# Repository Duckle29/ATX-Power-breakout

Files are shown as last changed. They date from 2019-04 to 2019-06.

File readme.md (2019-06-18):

# Pi ATX power breakout

This is just a simple board that breaks out the different rails of an ATX 24pin connector. It's mainly intented to be used for powering a Raspberry Pi and a 3D printer.

The board includes an EPS 4pin connector as well, allowing for up to 32A on the 12v rail. If you slightly overrun the rated 8A per cable, the 3 12v connectors will handle up to 36A (12A each). This is a 12.5% overload at 9A per cable. Most good cables/connectors should handle that.

The other rails can output 12A max, if the PSU can supply that on that rail.

The board also has a header for selecting how to control the PS_ON signal. It can either be controlled via a transistor controled by the RPi. Aditionally, the "Power Good" signal is also connected to the pi (through a voltage dividier).
Lastly, the I2C interface of the Pi is exposed on a 5 pin header, along with 5V 3V3 and Ground.

The 5V supply for the I2C connector and the Pi is selected through the the jumper JP1, while the 5V supply for the USB connector is selected via JP2. You can select between the 5V rail, or the 5V standby rail.

| Pin | Function |
|---|---|
| BCM17 | Power Good |
| BCM9  | Power On |
| BCM26 | BTN to GND |

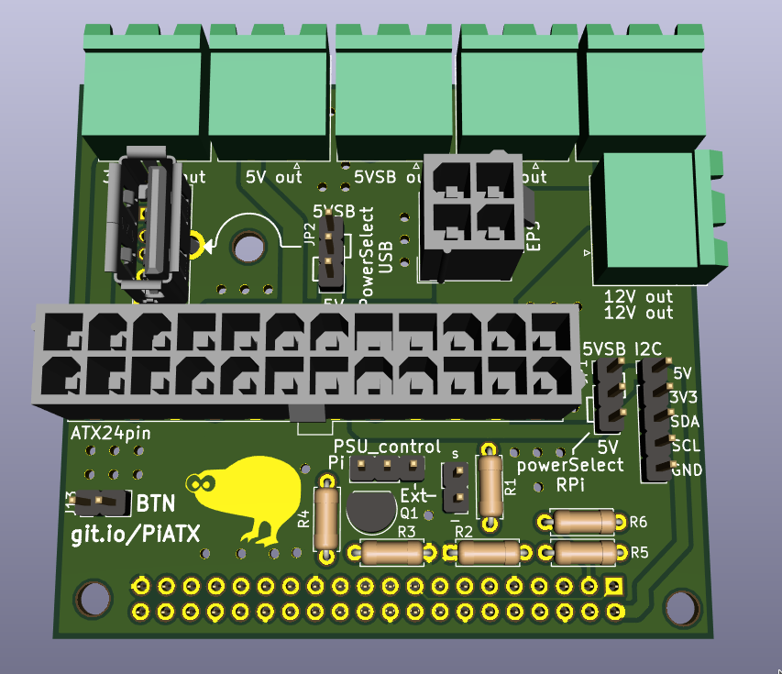
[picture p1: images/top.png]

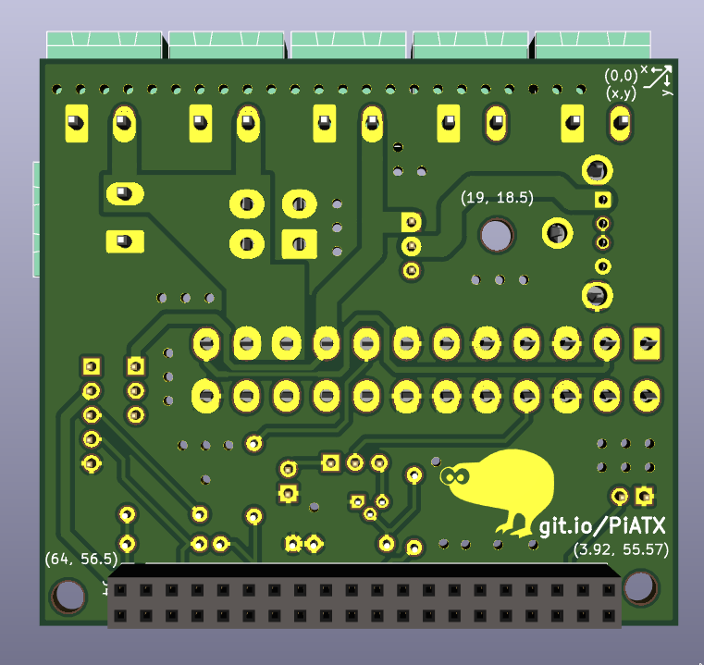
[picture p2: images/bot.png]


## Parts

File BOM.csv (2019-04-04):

Id | Designator | Package | Quantity | Designation | Supplier and ref
1 | REF**,REF**,REF** | MountingHole_3.2mm_M3_DIN965 | 3 | MountingHole_3.2mm_M3_DIN965
2 | R4 | R_Axial_DIN0207_L6.3mm_D2.5mm_P7.62mm_Horizontal | 1 | 1k
3 | J3 | USB_A_Stewart_SS-52100-001_Horizontal | 1 | USB_A
4 | G***,G*** | kiwi | 2 | LOGO
5 | J5 | Molex_Mini-Fit_Jr_5566-24A_2x12_P4.20mm_Vertical | 1 | ATX24pin
6 | J1 | PinHeader_1x05_P2.54mm_Vertical | 1 | I2C
7 | J2 | Molex_Mini-Fit_Jr_5566-04A_2x02_P4.20mm_Vertical | 1 | EPS
8 | J4 | PinSocket_2x20_P2.54mm_Vertical | 1 | Raspberry_Pi_2_3
9 | J7 | PinHeader_1x02_P2.54mm_Vertical | 1 | pson ext
10 | JP1,JP2 | PinHeader_1x03_P2.54mm_Vertical | 2 | powerSelect
11 | JP3 | PinHeader_1x03_P2.54mm_Vertical | 1 | PSU_control
12 | Q1 | TO-92 | 1 | Q_NPN_BCE
13 | J6,J11,J12 | PhoenixContact_MSTBA_2,5_2-G_1x02_P5.00mm_Horizontal | 3 | 12V out
14 | J8 | PhoenixContact_MSTBA_2,5_2-G_1x02_P5.00mm_Horizontal | 1 | 5V out
15 | J9 | PhoenixContact_MSTBA_2,5_2-G_1x02_P5.00mm_Horizontal | 1 | 5VSB out
16 | J10 | PhoenixContact_MSTBA_2,5_2-G_1x02_P5.00mm_Horizontal | 1 | 3V3 out
17 | R1 | R_Axial_DIN0207_L6.3mm_D2.5mm_P7.62mm_Horizontal | 1 | 5K6
18 | R2,R3,R5,R6 | R_Axial_DIN0207_L6.3mm_D2.5mm_P7.62mm_Horizontal | 4 | 10k

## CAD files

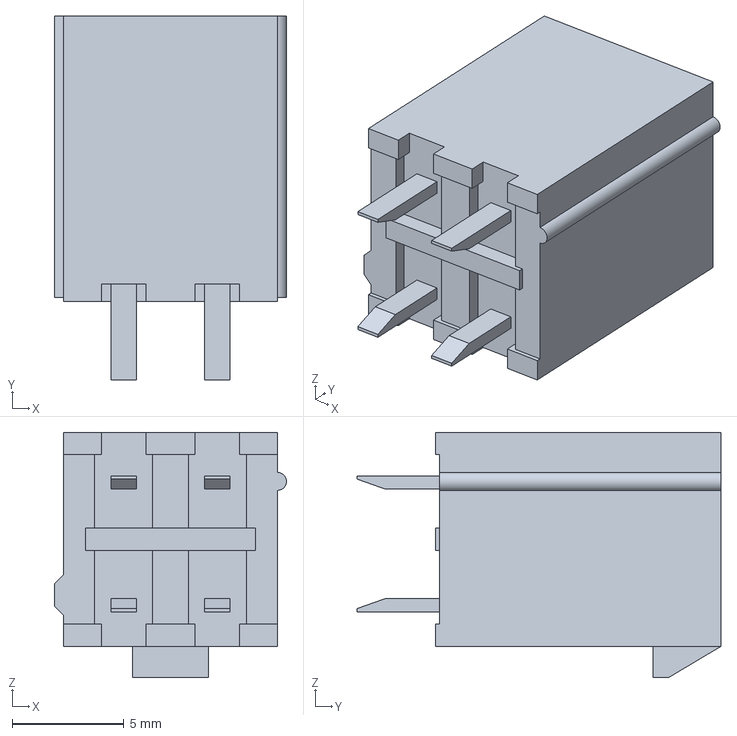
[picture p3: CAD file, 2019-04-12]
third-party-models/039281043.stp
10.4 x 16.3 x 11.0 mm

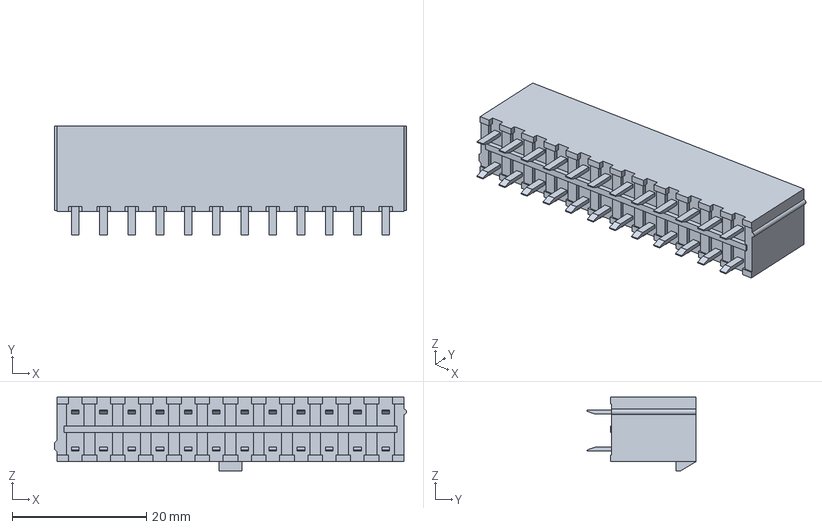
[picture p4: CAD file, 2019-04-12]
third-party-models/039281243.stp
52.4 x 16.3 x 11.0 mm

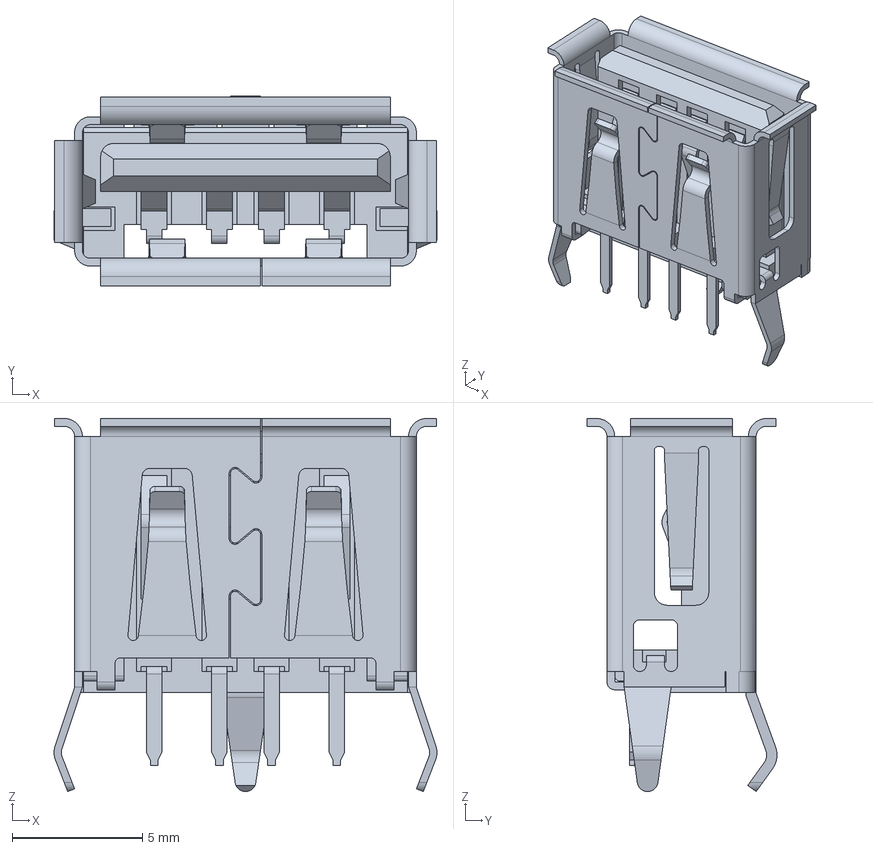
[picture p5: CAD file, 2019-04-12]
third-party-models/1050570001.stp
14.7 x 7.28 x 14.3 mm

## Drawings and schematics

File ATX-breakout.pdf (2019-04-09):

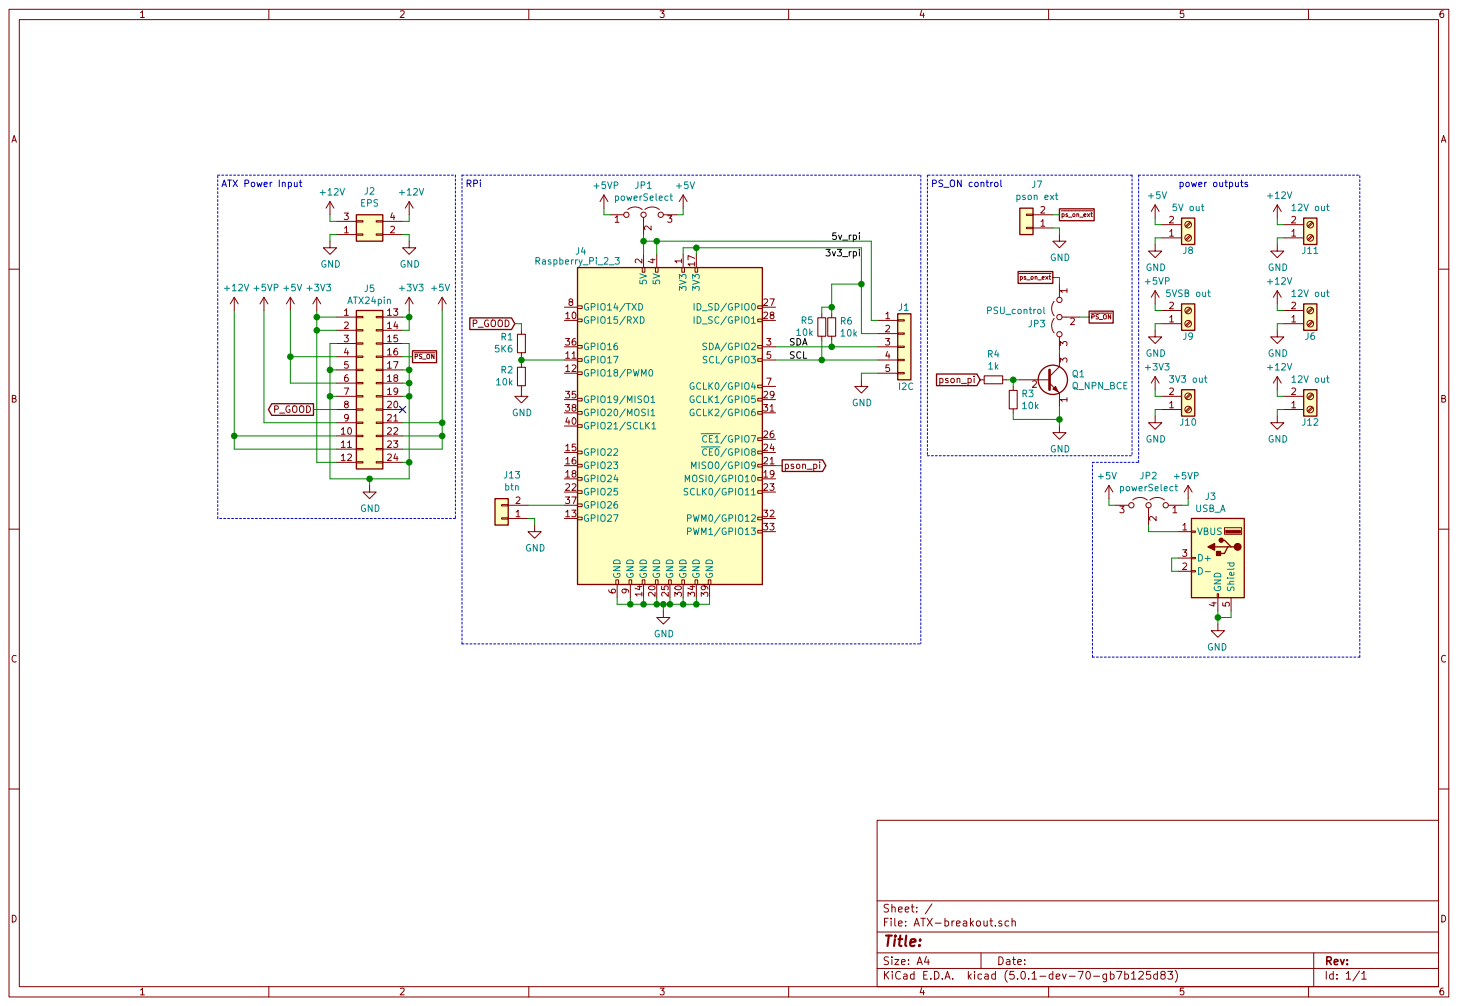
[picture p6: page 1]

10 | | 22
11 | | 23
12

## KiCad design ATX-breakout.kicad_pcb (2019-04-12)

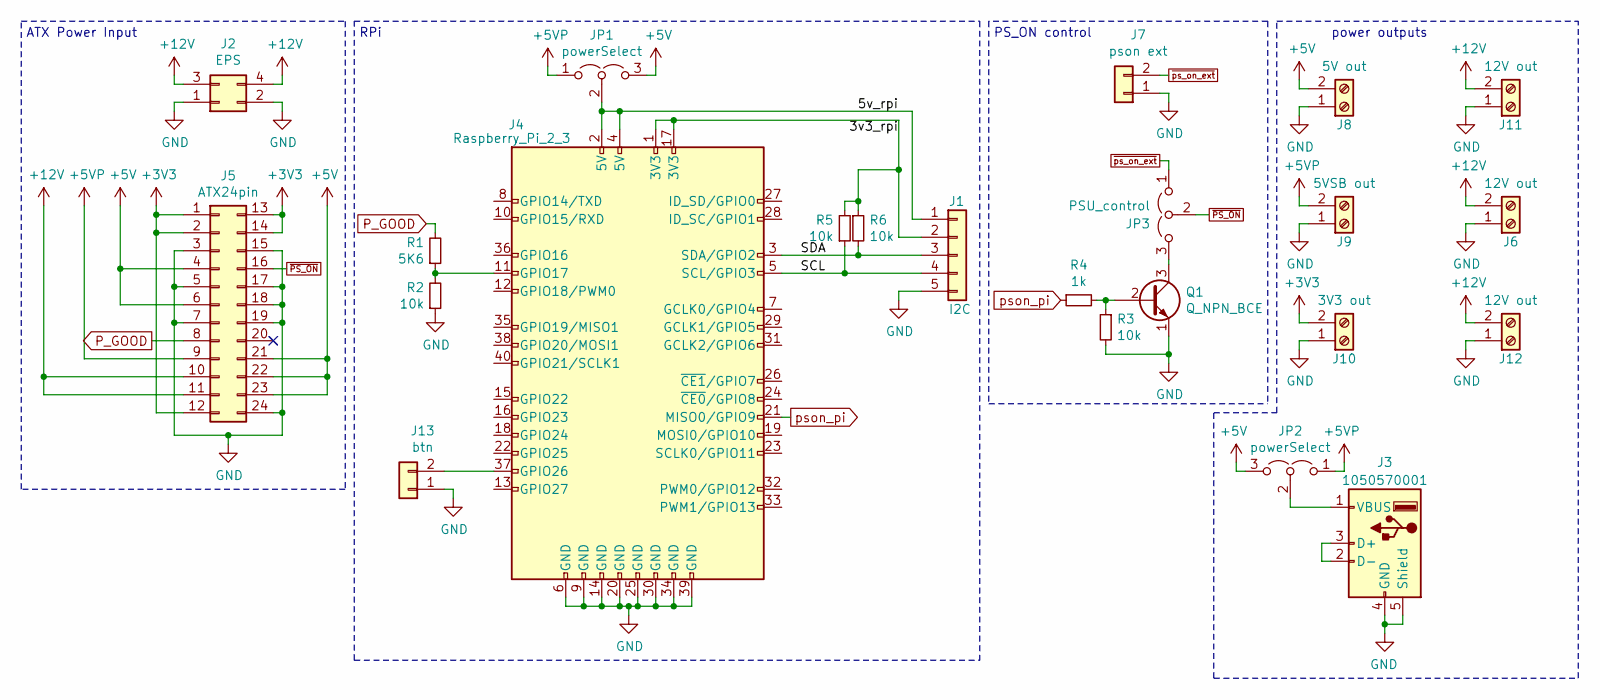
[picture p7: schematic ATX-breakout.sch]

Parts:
J1: I2C; PinHeader_1x05_P2.54mm_Vertical
J2: EPS; Molex_Mini-Fit_Jr_5566-04A_2x02_P4.20mm_Vertical
J3: 1050570001; USB_A_Molex_105057_Vertical
J4: Raspberry_Pi_2_3; PinSocket_2x20_P2.54mm_Vertical
J5: ATX24pin; Molex_Mini-Fit_Jr_5566-24A_2x12_P4.20mm_Vertical
J6, J11, J12: 12V out; PhoenixContact_MSTBA_2,5_2-G_1x02_P5.00mm_Horizontal
J7: pson ext; PinHeader_1x02_P2.54mm_Vertical
J8: 5V out; PhoenixContact_MSTBA_2,5_2-G_1x02_P5.00mm_Horizontal
J9: 5VSB out; PhoenixContact_MSTBA_2,5_2-G_1x02_P5.00mm_Horizontal
J10: 3V3 out; PhoenixContact_MSTBA_2,5_2-G_1x02_P5.00mm_Horizontal
J13: btn; PinHeader_1x02_P2.54mm_Vertical
JP1, JP2: powerSelect; PinHeader_1x03_P2.54mm_Vertical
JP3: PSU_control; PinHeader_1x03_P2.54mm_Vertical
Q1: Q_NPN_BCE; TO-92
R1: 5K6; R_Axial_DIN0207_L6.3mm_D2.5mm_P7.62mm_Horizontal
R2, R3, R5, R6: 10k; R_Axial_DIN0207_L6.3mm_D2.5mm_P7.62mm_Horizontal
R4: 1k; R_Axial_DIN0207_L6.3mm_D2.5mm_P7.62mm_Horizontal

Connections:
+3V3: J5.1, J5.2, J5.12, J5.13, J5.14, J10.2
+5V: J5.4, J5.6, J5.21, J5.22, J5.23, J8.2, JP1.3 (B), JP2.3 (B)
+5VP: J5.9, J9.2, JP1.1 (A), JP2.1 (A)
+12V: J2.3, J2.4, J5.10, J5.11, J6.2, J11.2, J12.2
/3v3_rpi: J1.2, J4.1 (3V3), J4.17 (3V3), R5.2, R6.1
/5v_rpi: J1.1, J4.2 (5V), J4.4 (5V), JP1.2 (C)
/SCL: J1.4, J4.5 (SCL/GPIO3), R5.1
/SDA: J1.3, J4.3 (SDA/GPIO2), R6.2
GND: J1.5, J2.1, J2.2, J3.4 (GND), J3.5 (Shield), J4.6 (GND), J4.9 (GND), J4.14 (GND), J4.20 (GND), J4.25 (GND), J4.30 (GND), J4.34 (GND), J4.39 (GND), J5.3, J5.5, J5.7, J5.15, J5.17, J5.18, J5.19, J5.24, J6.1, J7.1, J8.1, J9.1, J10.1, J11.1, J12.1, J13.1, Q1.1 (E), R2.1, R3.2
unnamed: J3.1 (VBUS), JP2.2 (C)
unnamed: J3.2 (D-), J3.3 (D+)
unnamed: J4.11 (GPIO17), R1.1, R2.2
unnamed: J4.37 (GPIO26), J13.2
unnamed: JP3.3 (B), Q1.3 (C)
unnamed: Q1.2 (B), R3.1, R4.2
P_GOOD: J5.8, R1.2
pson_pi: J4.21 (MISO0/GPIO9), R4.1
~PS_ON: J5.16, JP3.2 (C)
~ps_on_ext: J7.2, JP3.1 (A)

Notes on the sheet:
power outputs
PS_ON control
ATX Power Input
RPi

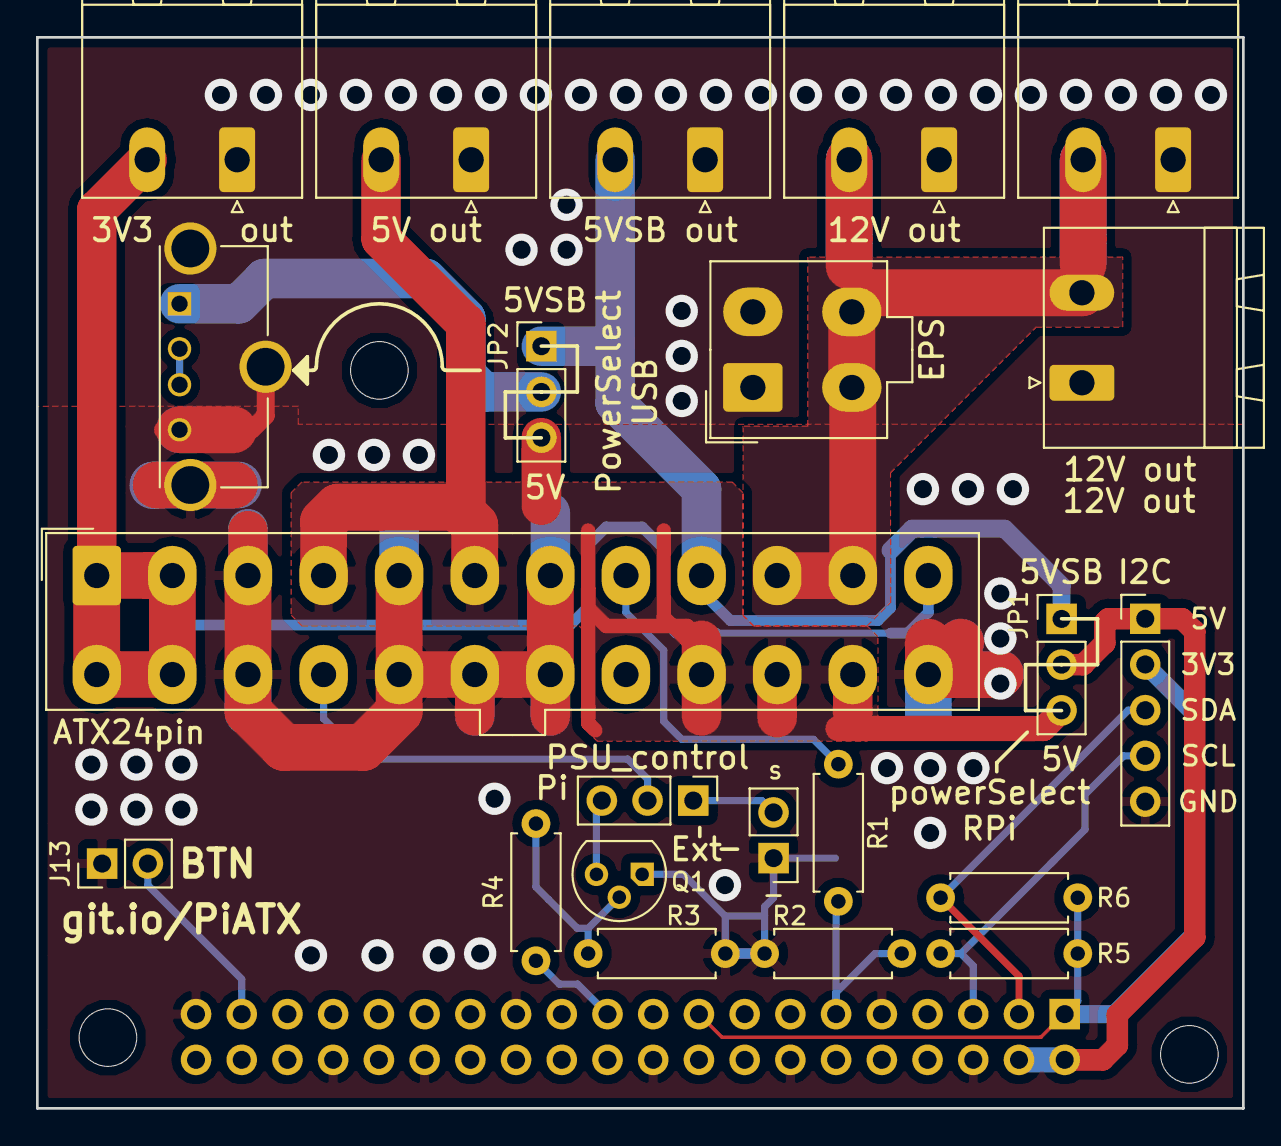
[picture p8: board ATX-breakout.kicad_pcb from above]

Board: 2 copper layers, 67.0 x 59.5 mm, 23 parts (1 on the bottom side), 19 nets.

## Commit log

2019-03-06 Finished up silkscreen
    [ATX-breakout.kicad_pcb, ATX-breakout.sch]
2019-03-06 added gerbers and BOM
    [ATX-breakout-B.Cu.gbr, ATX-breakout-B.Mask.gbr, ATX-breakout-B.SilkS.gbr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]
2019-03-06 Added readme
    [ATX-breakout.kicad_pcb]
2019-03-06 Made 12v pour solid, and increased 5v trace thicknesses
    [ATX-breakout-B.Cu.gbr, ATX-breakout-B.Mask.gbr, ATX-breakout-B.SilkS.gbr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]
2019-03-06 Fixed 3.3v shorted across lots of pins
    [ATX-breakout-B.Cu.gbr, ATX-breakout-B.Mask.gbr, ATX-breakout-B.SilkS.gbr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]
2019-03-06 fixed ground-pour weirdness
    [ATX-breakout-B.Cu.gbr, ATX-breakout-B.Mask.gbr, ATX-breakout-B.SilkS.gbr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]
2019-03-15 Switched to a more common transistor pinout
    [ATX-breakout-B.Cu.gbr, ATX-breakout-B.Mask.gbr, ATX-breakout-B.SilkS.gbr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]
2019-03-18 Added third 12v connector, fixed 12v-5v short
    [ATX-breakout-B.Cu.gbr, ATX-breakout-B.Mask.gbr, ATX-breakout-B.SilkS.gbr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]
2019-04-03 Added mounting holes
    [ATX-breakout-B.Cu.gbr, ATX-breakout-B.Mask.gbr, ATX-breakout-B.SilkS.gbr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]
2019-04-04 added schematic PDF and updated BOM
    [ATX-breakout.kicad_pcb, BOM.csv]
2019-04-09 Updated silkscreen
    [ATX-breakout-B.Cu.gbr, ATX-breakout-B.Mask.gbr, ATX-breakout-B.SilkS.gbr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]
2019-04-09 rotated EPS and improved ground routing
    [ATX-breakout.kicad_pcb, ATX-breakout.sch]
2019-04-09 Updated silk screen and gerbers
    [ATX-breakout-B.Cu.gbr, ATX-breakout-B.Mask.gbr, ATX-breakout-B.SilkS.gbr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]
2019-04-09 updated gerbers, silkscreen and renders
    [ATX-breakout-B.Cu.gbr, ATX-breakout-B.Mask.gbr, ATX-breakout-B.SilkS.gbr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]
2019-04-09 Updated pdf and readme
    [ATX-breakout.sch]
2019-04-12 Switched to vertical USB to clear pi ethernet jack
    [039281043.stp, 039281243.stp, 1050570001.stp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]
2019-04-12 Fixed some accidentally large traces
    [ATX-breakout-B.Cu.gbr, ATX-breakout-B.Mask.gbr, ATX-breakout-B.SilkS.gbr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]
